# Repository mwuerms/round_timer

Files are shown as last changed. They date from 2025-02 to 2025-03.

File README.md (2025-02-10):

# round_timer

a small round timer, watch, 

## Ideas

* minumum
    * timer (alarm)
        * multiple at the same time
    * simple to use
    * nice sounds, like from mp3, ogg, ...
    * runs from battery (LiPo or similar)
    * round display, GUI
* also nice
    * watch
    * sensors like humidity, pressure, temperatur, light, magnetic (compass), ...
    * vibra for alarm

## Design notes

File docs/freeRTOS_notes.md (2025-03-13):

# Notes on FreeRTOS

## Misc

+ `osDelay(100*portTICK_PERIOD_MS);` os delays 100 ms

## Links

+ [STM32 FreeRTOS](https://stm32world.com/wiki/STM32_FreeRTOS)
+ https://electronics.stackexchange.com/questions/290592/use-stm32-interrupt-with-freertos

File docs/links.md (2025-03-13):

# Links

## STM32 examples

+ [STM32 FreeRTOS](https://stm32world.com/wiki/STM32_FreeRTOS)
+ [STM32L4 LL examples](https://github.com/STMicroelectronics/STM32CubeL4/tree/master/Projects/NUCLEO-L496ZG/Examples_LL)

## try this example/lib

+ [offpic / GC9A01-DMA-TFT-STM32-STM32F401-CLOCK](https://github.com/offpic/GC9A01-DMA-TFT-STM32-STM32F401-CLOCK)

## Inspiration

+ [Youtube GC9A01 DMA TFT STM32 STM32F401 CLOCK](https://www.youtube.com/watch?v=id6IK4ea0z8)
  + [offpic / GC9A01-DMA-TFT-STM32-STM32F401-CLOCK](https://github.com/offpic/GC9A01-DMA-TFT-STM32-STM32F401-CLOCK)
  + [STM32_Lib_TFT_ST7789](https://github.com/GolinskiyKonstantin/STM32_Lib_TFT_ST7789)
+ [Exboom (seems simple for STM32)](https://github.com/Exboom/GC9A01)
+ [seemingly simple GC9A01 example using Bodmer TFT_eSPI](https://elektro.turanis.de/html/prj441/index.html)
+ [Bodmer TFT_eSPI](https://github.com/Bodmer/TFT_eSPI)
+ [Waveshare GC9A01 Display (not the exact one)](https://www.waveshare.com/1.28inch-lcd-module.htm)
+ [STM32 + GC9A01 + Waveshare](https://www.waveshare.com/wiki/1.28inch_LCD_Module)
+ [VolosR + watchESP](https://github.com/VolosR/watchESP)
+ [printminopn](https://github.com/printminion/GC9A01-xiao-ESP32C3)

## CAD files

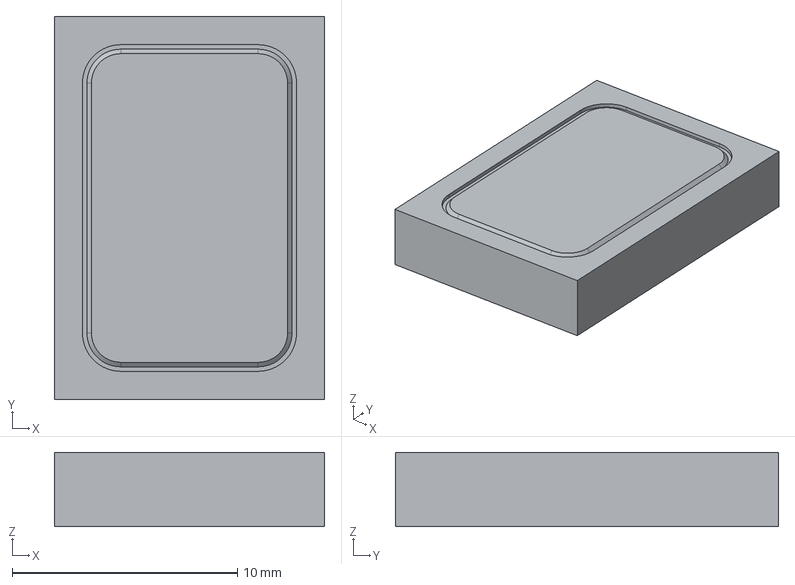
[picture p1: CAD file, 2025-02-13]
freecad/parts/speaker-CMS-171233-18SP-X8.step
12.0 x 17.0 x 3.30 mm

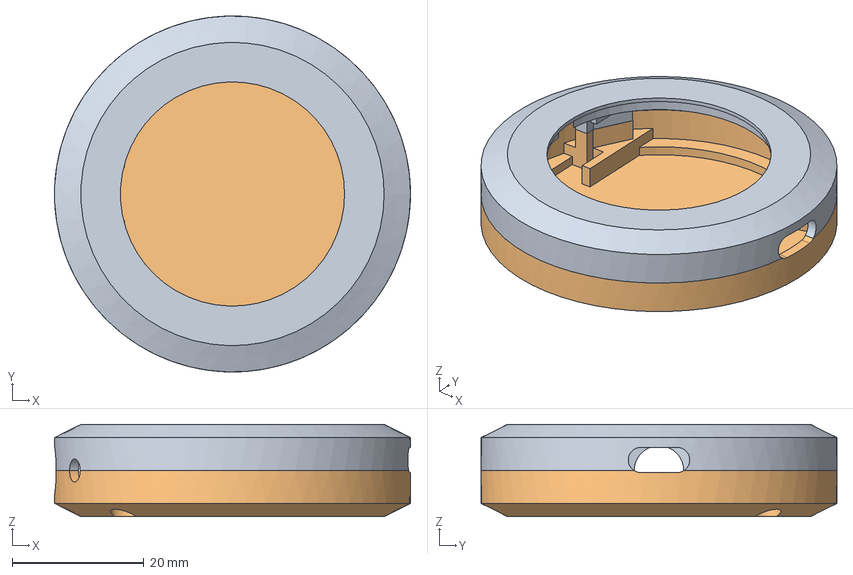
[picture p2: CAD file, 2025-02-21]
freecad/round_timer04.FCStd
54.0 x 54.0 x 14.0 mm
case top
case bottom

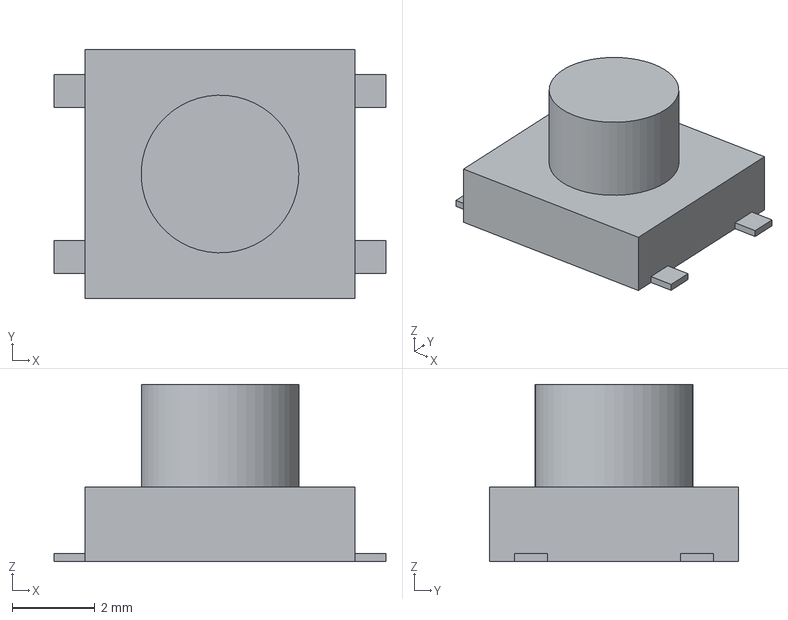
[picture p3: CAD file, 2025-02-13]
freecad/parts/button-EVPBT3G4A000.step
8.00 x 6.00 x 4.27 mm

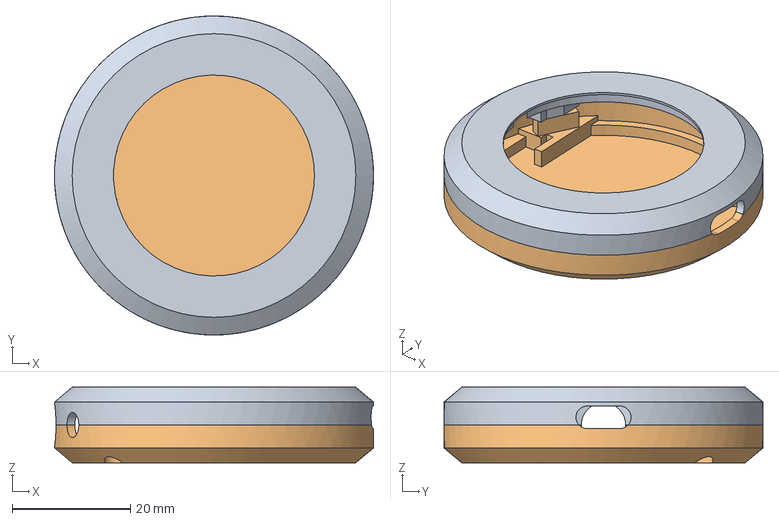
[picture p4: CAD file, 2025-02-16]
freecad/round_timer03.FCStd
54.0 x 54.0 x 12.8 mm
case top
case bottom

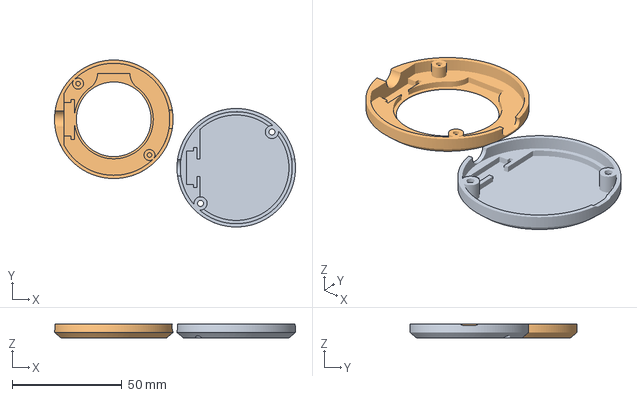
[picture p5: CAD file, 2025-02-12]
freecad/mockup02_case.3mf
109.8 x 76.0 x 6.40 mm
mockup02_case_bottom
mockup02_case_top

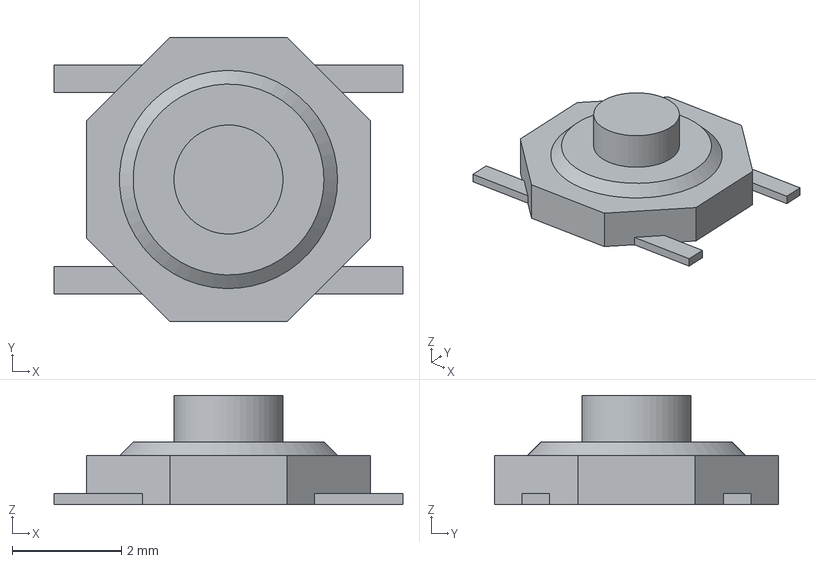
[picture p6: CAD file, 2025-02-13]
freecad/parts/button-PTS526SM20SMTR21_LFS.step
6.40 x 5.20 x 2.00 mm

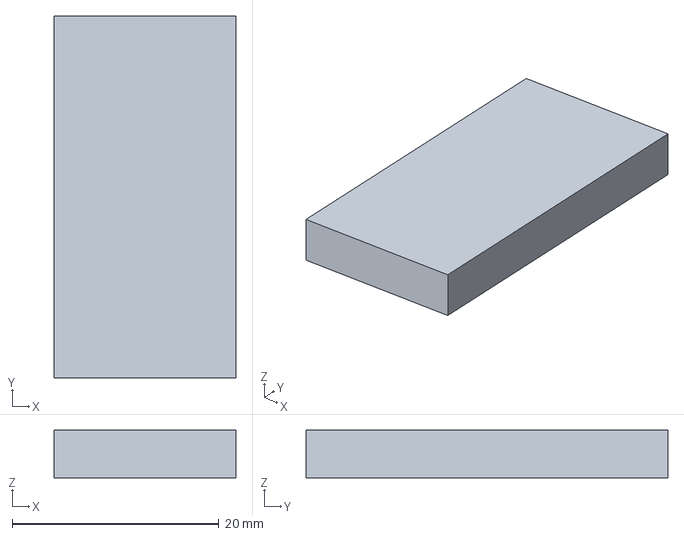
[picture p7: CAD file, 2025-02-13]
freecad/parts/battery.FCStd
17.6 x 35.0 x 4.60 mm

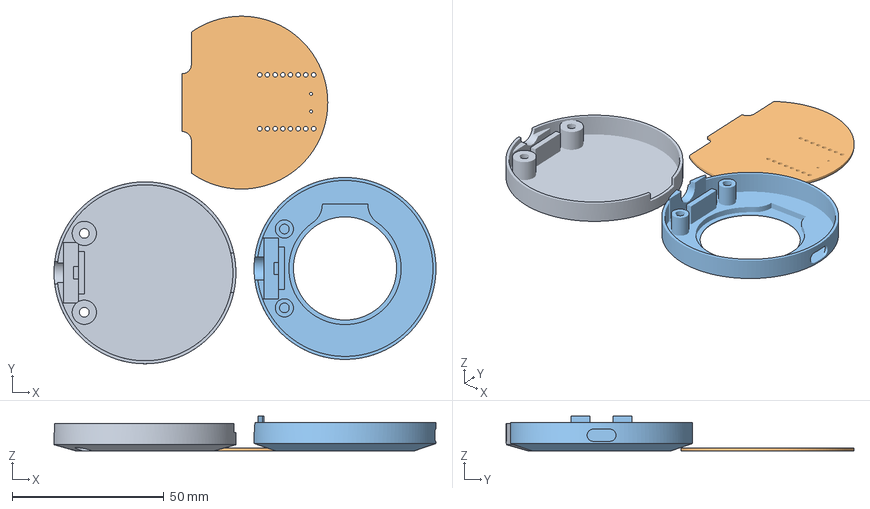
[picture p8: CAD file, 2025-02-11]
freecad/mockup01_case.3mf
126.0 x 114.6 x 11.4 mm
mockup01_case_bottom
mockup01_pcb
mockup01_case_top

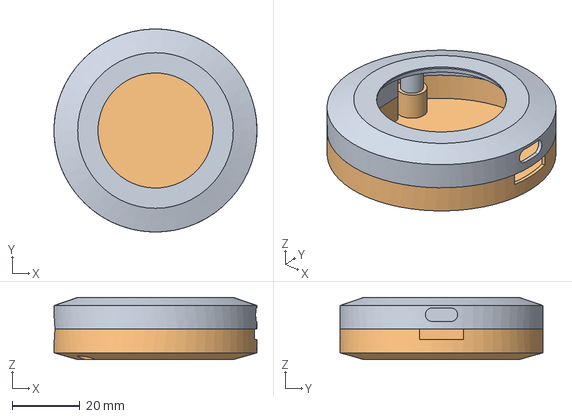
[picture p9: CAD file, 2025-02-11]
freecad/round_timer01.FCStd
60.0 x 60.0 x 18.4 mm
case top
case bottom

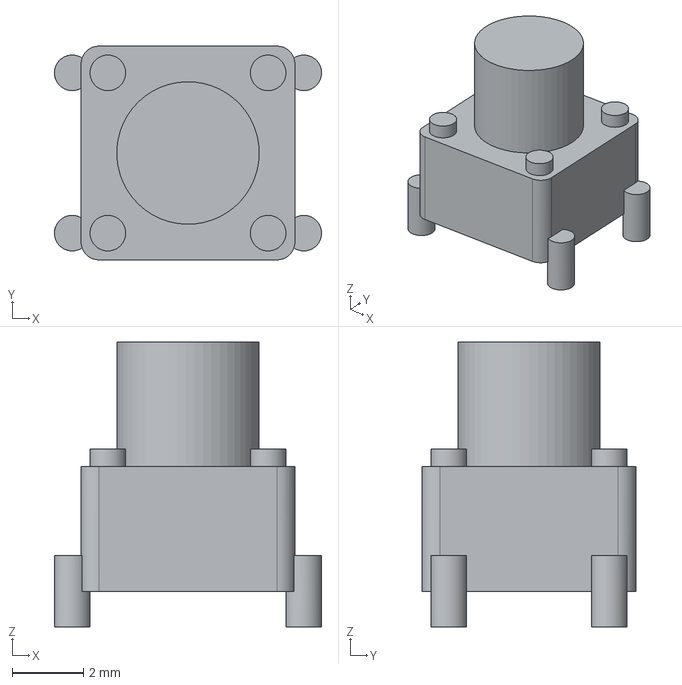
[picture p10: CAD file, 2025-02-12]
freecad/parts/button-TS02-66-70-BK-160-SCR.step
7.50 x 6.00 x 8.00 mm

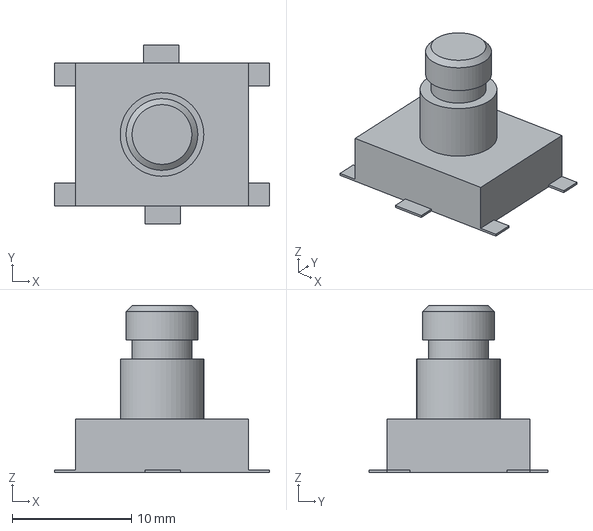
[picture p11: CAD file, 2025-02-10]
freecad/parts/rotary_encoder_PEC11S-929K-H0015.step
18.0 x 15.0 x 14.0 mm

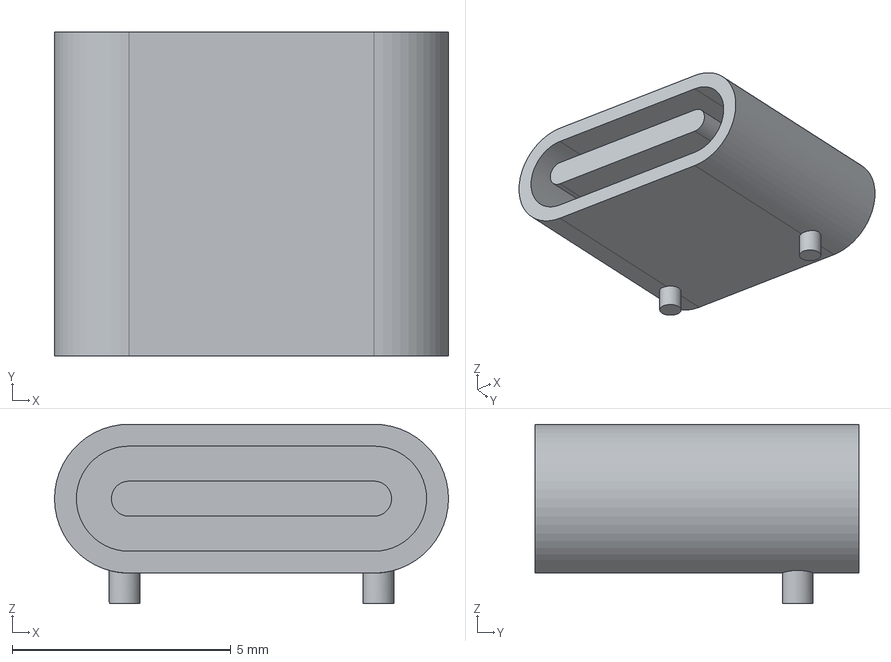
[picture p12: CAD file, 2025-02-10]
freecad/parts/USB4110-USB4110_CGT.step
9.00 x 7.40 x 4.10 mm

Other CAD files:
freecad/round_timer02.FCStd
freecad/parts/battery-IP461834.step
freecad/parts/button.FCStd
freecad/parts/speaker.FCStd
freecad/parts/rotary_encoder_PEC11S.FCStd
freecad/parts/USB4110.FCStd
freecad/parts/PER601-P117-N0015.stp
freecad/parts/dfplayer_pcb-player.step
freecad/parts/dfplayer_pcb.FCStd
freecad/parts/rotary_encoder_PEC11R-4215K-S0024.FCStd
freecad/parts/rotary_encoder_PEC11R-4215K-S0024.step
freecad/parts/round_1.28_inch_display.FCStd
freecad/parts/round_1.28_inch_display.step
freecad/parts/round_1.28_inch_display_cut.step
freecad/parts/speaker_CMS-3047-18L300-speaker.step

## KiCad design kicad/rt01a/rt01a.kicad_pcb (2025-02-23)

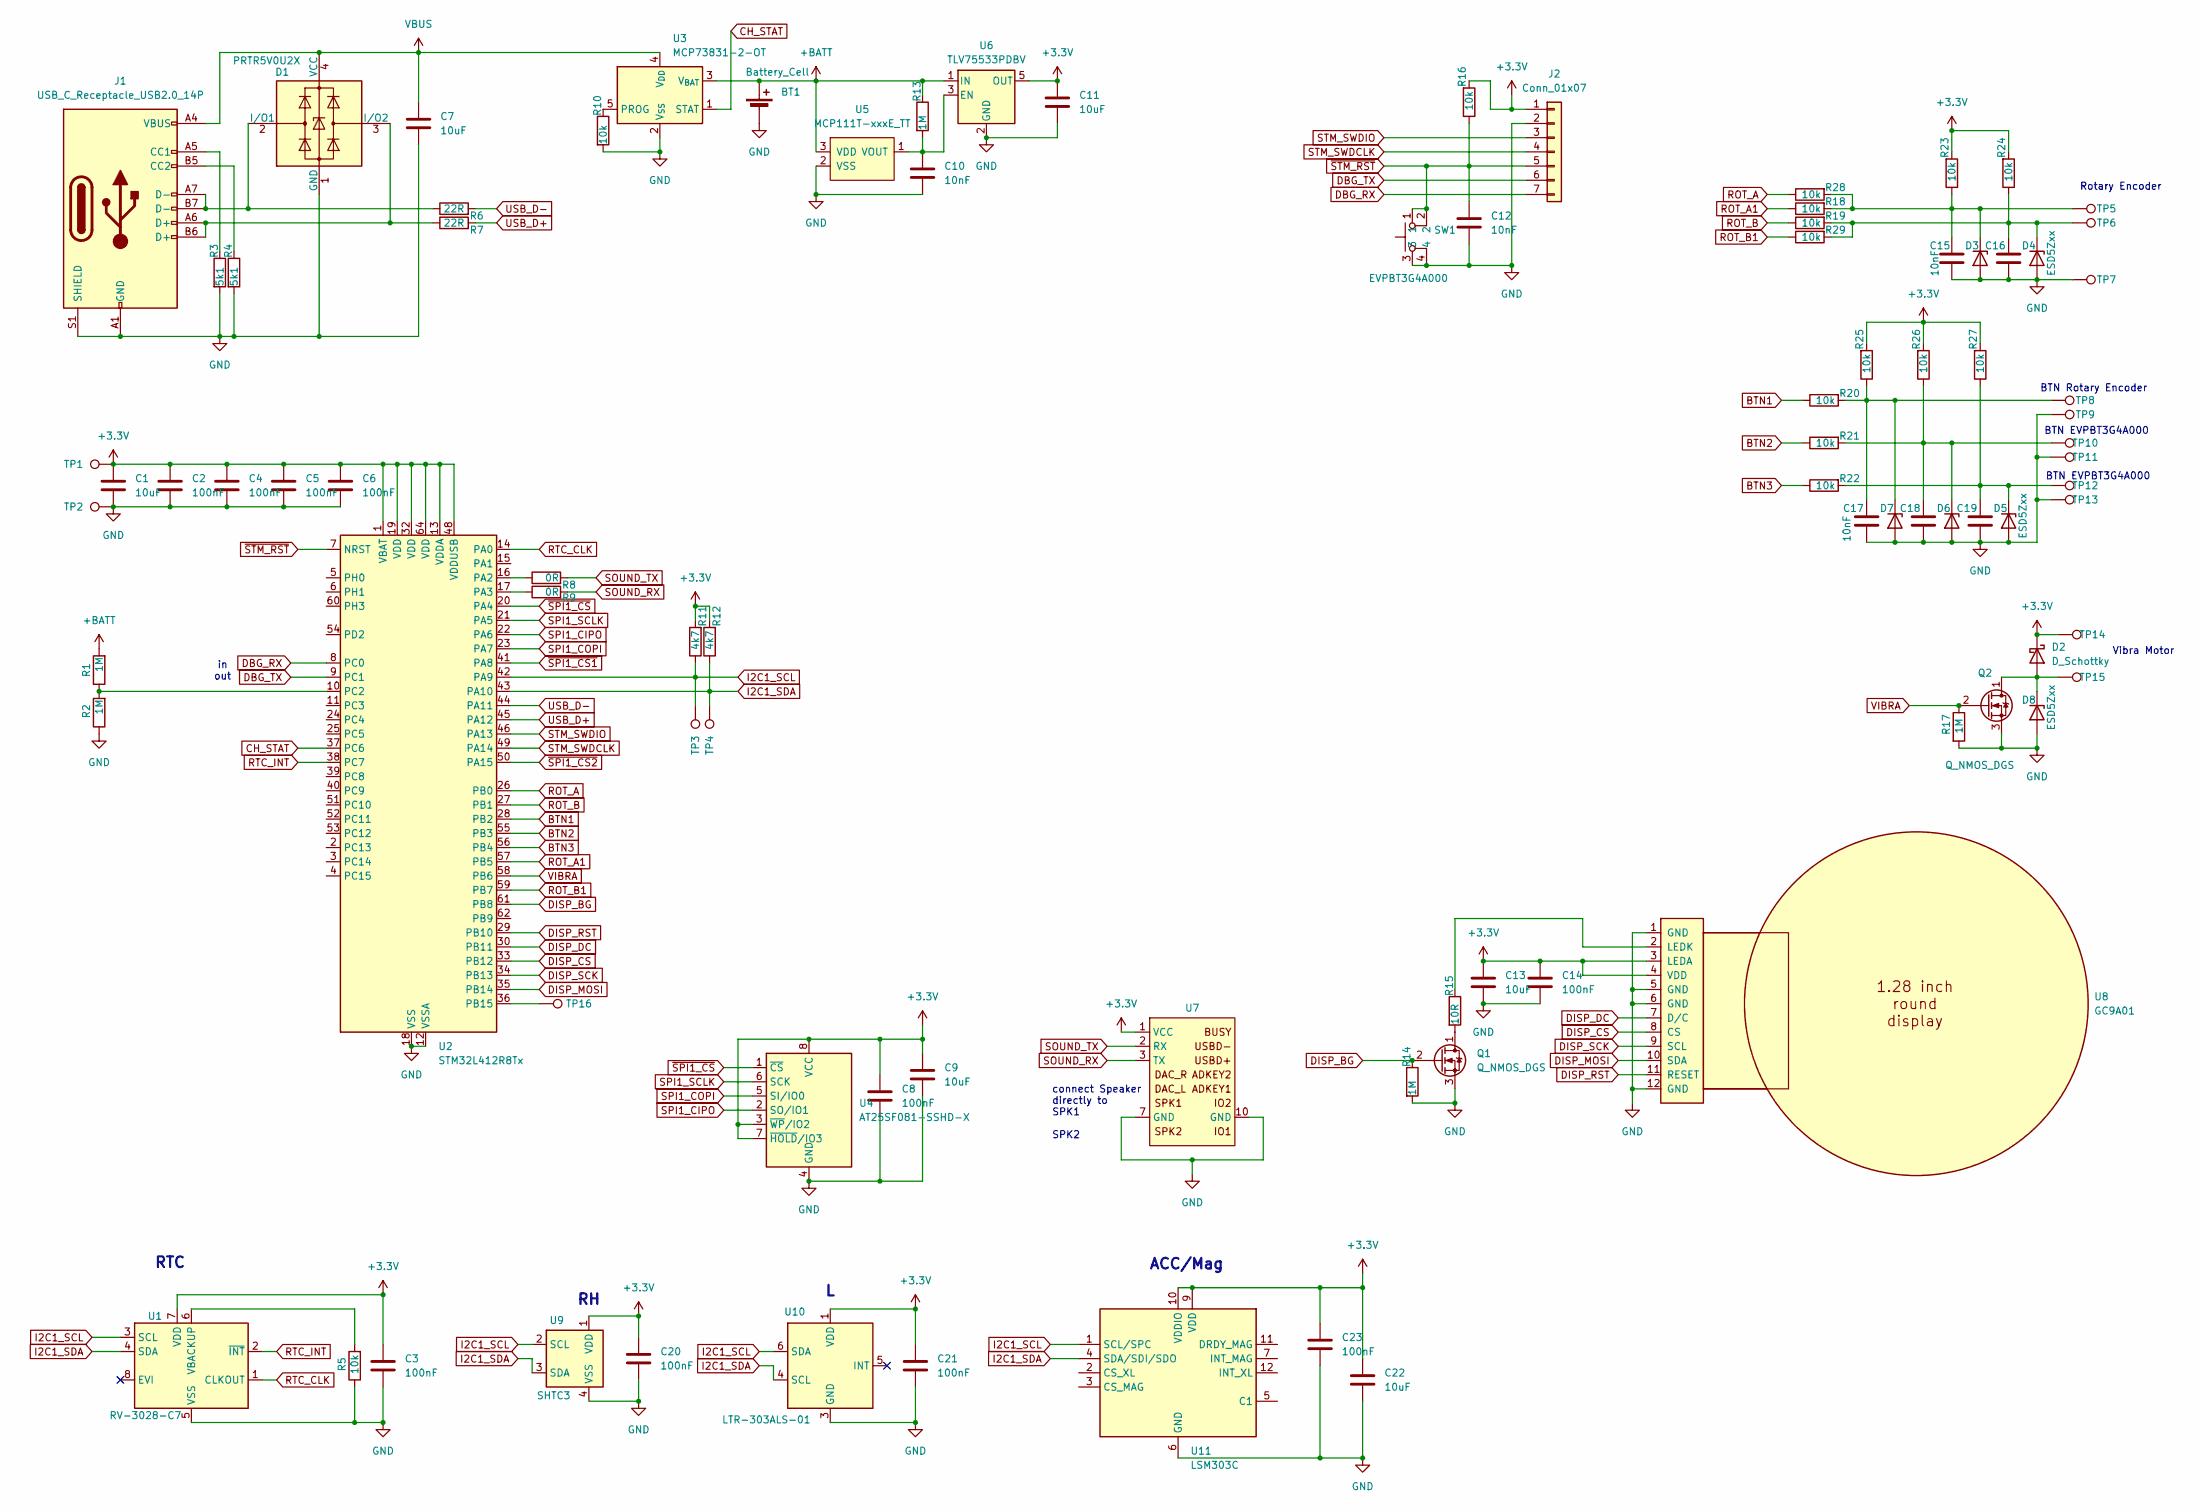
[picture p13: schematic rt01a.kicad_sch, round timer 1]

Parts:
BT1: Battery_Cell; PinHeader_1x02_P2.54mm_Vertical
C1, C7, C9, C11, C13, C22: 10uF; C_0805_2012Metric_Pad1.18x1.45mm_HandSolder
C2, C3, C4, C5, C6, C8, C14, C20, C21, C23: 100nF; C_0603_1608Metric_Pad1.08x0.95mm_HandSolder
C10, C12, C15, C16, C17, C18, C19: 10nF; C_0603_1608Metric_Pad1.08x0.95mm_HandSolder
D1: PRTR5V0U2X; SOT-143
D2: D_Schottky; D_SOD-523
D3, D4, D5, D6, D7, D8: ESD5Zxx; D_SMF
J1: USB_C_Receptacle_USB2.0_14P; USB_C_Receptacle_GCT_USB4110
J2: Conn_01x07; PinHeader_1x07_P1.27mm_Vertical
Q1, Q2: Q_NMOS_DGS; SOT-23-3
R1, R2, R13, R14, R17: 1M; R_0603_1608Metric_Pad0.98x0.95mm_HandSolder
R3, R4: 5k1; R_0603_1608Metric_Pad0.98x0.95mm_HandSolder
R5, R10, R16, R18, R19, R20, R21, R22, R23, R24, R25, R26, R27, R28, R29: 10k; R_0603_1608Metric_Pad0.98x0.95mm_HandSolder
R6, R7: 22R; R_0603_1608Metric_Pad0.98x0.95mm_HandSolder
R8, R9: 0R; R_0603_1608Metric_Pad0.98x0.95mm_HandSolder
R11, R12: 4k7; R_0603_1608Metric_Pad0.98x0.95mm_HandSolder
R15: 10R; R_0603_1608Metric_Pad0.98x0.95mm_HandSolder
SW1: EVPBT3G4A000; EVPBT3
TP1, TP2, TP3, TP4, TP5, TP6, TP7, TP8, TP9, TP10, TP11, TP12, TP13, TP14, TP15, TP16: TestPoint; TestPoint_Pad_D1.0mm
U1: RV-3028-C7; MicroCrystal_C7_SON-8_1.5x3.2mm_P0.9mm
U2: STM32L412R8Tx; LQFP-64_10x10mm_P0.5mm
U3: MCP73831-2-OT; SOT-23-5
U4: AT25SF081-SSHD-X; SOIC-8_3.9x4.9mm_P1.27mm
U5: MCP111T-xxxE_TT; SOT-23-3
U6: TLV75533PDBV; SOT-23-5
U7: DFPlayer_Mini-TF-16P_Minimal
U8: GC9A01; FP-128HR01A
U9: SHTC3; Sensirion_DFN-4-1EP_2x2mm_P1mm_EP0.7x1.6mm
U10: LTR-303ALS-01; Lite-On_LTR-303ALS-01
U11: LSM303C; LGA-12_2x2mm_P0.5mm

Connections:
+3.3V: C1.1, C2.1, C3.1, C4.1, C5.1, C6.1, C8.1, C9.1, C11.1, C13.1, C14.1, C20.1, C21.1, C22.1, C23.1, D2.1 (K), J2.1, R11.2, R12.2, R16.2, R23.2, R24.2, R25.2, R26.2, R27.2, TP1.1, TP14.1, U1.7 (VDD), U2.1 (VBAT), U2.13 (VDDA), U2.19 (VDD), U2.32 (VDD), U2.48 (VDDUSB), U2.64 (VDD), U4.3 (~WP/IO2), U4.7 (~HOLD/IO3), U4.8 (VCC), U6.5 (OUT), U7.1 (VCC), U8.3 (LEDA), U8.4 (VDD), U9.1 (VDD), U10.1 (VDD), U11.9 (VDD), U11.10 (VDDIO)
+BATT: BT1.1 (+), R1.2, R13.1, U3.3 (V_{BAT}), U5.3 (VDD), U6.1 (IN)
BTN1: R20.1, U2.28 (PB2)
BTN2: R21.1, U2.55 (PB3)
BTN3: R22.1, U2.56 (PB4)
CH_STAT: U2.37 (PC6), U3.1 (STAT)
DBG_RX: J2.7, U2.8 (PC0)
DBG_TX: J2.6, U2.9 (PC1)
DISP_BG: Q1.2 (G), R14.1, U2.61 (PB8)
DISP_CS: U2.33 (PB12), U8.8 (CS)
DISP_DC: U2.30 (PB11), U8.7 (D/C)
DISP_MOSI: U2.35 (PB14), U8.10 (SDA)
DISP_RST: U2.29 (PB10), U8.11 (RESET)
DISP_SCK: U2.34 (PB13), U8.9 (SCL)
GND: BT1.2 (-), C1.2, C2.2, C3.2, C4.2, C5.2, C6.2, C7.2, C8.2, C9.2, C10.2, C11.2, C12.2, C13.2, C14.2, C15.2, C16.2, C17.2, C18.2, C19.2, C20.2, C21.2, C22.2, C23.2, D1.1 (GND), D3.2 (A), D4.2 (A), D5.2 (A), D6.2 (A), D7.2 (A), D8.2 (A), J1.A1 (GND), J1.A12 (GND), J1.B1 (GND), J1.B12 (GND), J1.S1 (SHIELD), J2.2, Q1.3 (S), Q2.3 (S), R2.1, R3.2, R4.2, R5.1, R10.2, R14.2, R17.2, SW1.3, SW1.4, TP2.1, TP7.1, TP9.1, TP11.1, TP13.1, U1.5 (VSS), U2.12 (VSSA), U2.18 (VSS), U2.31 (VSS), U2.47 (VSS), U2.63 (VSS), U3.2 (V_{SS}), U4.4 (GND), U5.2 (VSS), U6.2 (GND), U7.7 (GND), U7.10 (GND), U8.1 (GND), U8.5 (GND), U8.6 (GND), U8.12 (GND), U9.4 (VSS), U10.3 (GND), U11.6 (GND), U11.8 (GND)
I2C1_SCL: R11.1, TP3.1, U1.3 (SCL), U2.42 (PA9), U9.2 (SCL), U10.6 (SDA), U11.1 (SCL/SPC)
I2C1_SDA: R12.1, TP4.1, U1.4 (SDA), U2.43 (PA10), U9.3 (SDA), U10.4 (SCL), U11.4 (SDA/SDI/SDO)
unnamed: D1.2 (I/O1), J1.A7 (D-), J1.B7 (D-), R6.1
unnamed: D1.3 (I/O2), J1.A6 (D+), J1.B6 (D+), R7.1
unnamed: D2.2 (A), D8.1 (K), Q2.1 (D), TP15.1
unnamed: C15.1, D3.1 (K), R18.2, R23.1, R28.2, TP5.1
unnamed: C16.1, D4.1 (K), R19.2, R24.1, R29.2, TP6.1
unnamed: C19.1, D5.1 (K), R22.2, R27.1, TP12.1
unnamed: C18.1, D6.1 (K), R21.2, R26.1, TP10.1
unnamed: C17.1, D7.1 (K), R20.2, R25.1, TP8.1
unnamed: J1.A5 (CC1), R3.1
unnamed: J1.B5 (CC2), R4.1
unnamed: Q1.1 (D), R15.2
unnamed: R5.2, U1.6 (VBACKUP)
unnamed: R8.1, U2.16 (PA2)
unnamed: R9.1, U2.17 (PA3)
unnamed: TP16.1, U2.36 (PB15)
unnamed: R1.1, R2.2, U2.10 (PC2)
unnamed: R10.1, U3.5 (PROG)
unnamed: C10.1, R13.2, U5.1 (VOUT), U6.3 (EN)
unnamed: R15.1, U8.2 (LEDK)
ROT_A: R28.1, U2.26 (PB0)
ROT_A1: R18.1, U2.57 (PB5)
ROT_B: R19.1, U2.27 (PB1)
ROT_B1: R29.1, U2.59 (PB7)
RTC_CLK: U1.1 (CLKOUT), U2.14 (PA0)
RTC_INT: U1.2 (~INT), U2.38 (PC7)
SOUND_RX: R9.2, U7.3 (TX)
SOUND_TX: R8.2, U7.2 (RX)
SPI1_CIPO: U2.22 (PA6), U4.2 (SO/IO1)
SPI1_COPI: U2.23 (PA7), U4.5 (SI/IO0)
SPI1_SCLK: U2.21 (PA5), U4.6 (SCK)
STM_SWDCLK: J2.4, U2.49 (PA14)
STM_SWDIO: J2.3, U2.46 (PA13)
USB_D+: R7.2, U2.45 (PA12)
USB_D-: R6.2, U2.44 (PA11)
VBUS: C7.1, D1.4 (VCC), J1.A4 (VBUS), J1.A9 (VBUS), J1.B4 (VBUS), J1.B9 (VBUS), U3.4 (V_{DD})
VIBRA: Q2.2 (G), R17.1, U2.58 (PB6)
~SPI1_CS1: U2.41 (PA8)
~SPI1_CS2: U2.50 (PA15)
~SPI1_CS: U2.20 (PA4), U4.1 (~CS)
~STM_RST: C12.1, J2.5, R16.1, SW1.1, SW1.2, U2.7 (NRST)

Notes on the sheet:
BTN EVPBT3G4A000
Rotary Encoder
RTC
connect Speaker directly to SPK1 SPK2
Vibra Motor
BTN Rotary Encoder
ACC/Mag
in out

Board: 4 copper layers, 93 parts (85 on the bottom side), 55 nets, no tracks yet.

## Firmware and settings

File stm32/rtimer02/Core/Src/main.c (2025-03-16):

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
/* Includes ------------------------------------------------------------------*/
#include "main.h"
#include "cmsis_os.h"
#include "spi.h"
#include "gpio.h"

/* USER CODE BEGIN Includes */
#include "disp.h"

/* USER CODE END Includes */


void SystemClock_Config(void);
void MX_FREERTOS_Init(void);
/**
  * @brief  The application entry point.
  * @retval int
  */
int main(void)
{

  /* MCU Configuration--------------------------------------------------------*/

  /* Reset of all peripherals, Initializes the Flash interface and the Systick. */
  HAL_Init();

  /* Configure the system clock */
  SystemClock_Config();

  /* Initialize all configured peripherals */
  MX_GPIO_Init();
  MX_SPI2_Init();
  /* USER CODE BEGIN 2 */

	HAL_GPIO_WritePin(DBG0_GPIO_Port, DBG0_Pin, GPIO_PIN_RESET);
	HAL_GPIO_WritePin(DBG1_GPIO_Port, DBG1_Pin, GPIO_PIN_RESET);
	HAL_GPIO_WritePin(DBG0_GPIO_Port, DBG0_Pin, GPIO_PIN_SET);
	HAL_GPIO_WritePin(DBG1_GPIO_Port, DBG1_Pin, GPIO_PIN_SET);
	HAL_GPIO_WritePin(DBG0_GPIO_Port, DBG0_Pin, GPIO_PIN_RESET);
	HAL_GPIO_WritePin(DBG1_GPIO_Port, DBG1_Pin, GPIO_PIN_RESET);


	for(volatile uint32_t cnt = 0; cnt < 10000; cnt++); // 6 ms
	HAL_GPIO_WritePin(DBG0_GPIO_Port, DBG0_Pin, GPIO_PIN_SET);
	for(volatile uint32_t cnt = 0; cnt < 20000; cnt++); // 13 ms
	HAL_GPIO_WritePin(DBG1_GPIO_Port, DBG1_Pin, GPIO_PIN_SET);
	for(volatile uint32_t cnt = 0; cnt < 30000; cnt++); // 19 ms
	HAL_GPIO_WritePin(DBG0_GPIO_Port, DBG0_Pin, GPIO_PIN_RESET);
	for(volatile uint32_t cnt = 0; cnt < 500000; cnt++); // 347 ms
	HAL_GPIO_WritePin(DBG1_GPIO_Port, DBG1_Pin, GPIO_PIN_RESET);

	// 50 ms -> 30000/19 * 50 = 79000
	// 100 ms -> 160000
	// 150 ms -> 240000
	//for(volatile uint32_t cnt = 0; cnt < (1*80000); cnt++); // 56 ms
	for(volatile uint32_t cnt = 0; cnt < (1*79000); cnt++); // 55 ms
	HAL_GPIO_WritePin(DBG0_GPIO_Port, DBG0_Pin, GPIO_PIN_SET);
	//for(volatile uint32_t cnt = 0; cnt < (2*80000); cnt++); // 110 ms
	for(volatile uint32_t cnt = 0; cnt < (2*79000); cnt++); // 110 ms
	HAL_GPIO_WritePin(DBG1_GPIO_Port, DBG1_Pin, GPIO_PIN_SET);
	//for(volatile uint32_t cnt = 0; cnt < (3*80000); cnt++); // 166 ms
	for(volatile uint32_t cnt = 0; cnt < (3*79000); cnt++); // 166 ms
	HAL_GPIO_WritePin(DBG1_GPIO_Port, DBG1_Pin, GPIO_PIN_RESET);
	HAL_GPIO_WritePin(DBG0_GPIO_Port, DBG0_Pin, GPIO_PIN_RESET);

	disp_init();
	disp_rotation(6, 0, 0); // correct rotation for this project

	app_init();
  	usr_in_init();


	HAL_GPIO_WritePin(DBG0_GPIO_Port, DBG0_Pin, GPIO_PIN_SET);
	HAL_GPIO_WritePin(DBG1_GPIO_Port, DBG1_Pin, GPIO_PIN_SET);

	//disp_print(20, 80, DISP_COLOR_RED, DISP_COLOR_WHITE, 1, &Font_16x26, 0, ".-=' INIT '=-.");

	HAL_GPIO_WritePin(DBG0_GPIO_Port, DBG0_Pin, GPIO_PIN_RESET);
	HAL_GPIO_WritePin(DBG1_GPIO_Port, DBG1_Pin, GPIO_PIN_RESET);
  /* USER CODE END 2 */

  /* Init scheduler */
  osKernelInitialize();

  /* Call init function for freertos objects (in cmsis_os2.c) */
  MX_FREERTOS_Init();

  /* Start scheduler */
  osKernelStart();

  /* We should never get here as control is now taken by the scheduler */

  /* Infinite loop */
  /* USER CODE BEGIN WHILE */
  while (1)
  {
    /* USER CODE END WHILE */

    /* USER CODE BEGIN 3 */
  }
  /* USER CODE END 3 */
}

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
/**
  * @brief  Period elapsed callback in non blocking mode
  * @note   This function is called  when TIM1 interrupt took place, inside
  * HAL_TIM_IRQHandler(). It makes a direct call to HAL_IncTick() to increment
  * a global variable "uwTick" used as application time base.
  * @param  htim : TIM handle
  * @retval None
  */
void HAL_TIM_PeriodElapsedCallback(TIM_HandleTypeDef *htim)
{
  if (htim->Instance == TIM1) {
    HAL_IncTick();
  }
}

/**
  * @brief  This function is executed in case of error occurrence.
  * @retval None
  */
void Error_Handler(void)
{
  /* USER CODE BEGIN Error_Handler_Debug */
  /* User can add his own implementation to report the HAL error return state */
  __disable_irq();
  while (1)
  {
  }
  /* USER CODE END Error_Handler_Debug */
}

#ifdef  USE_FULL_ASSERT
/**
  * @brief  Reports the name of the source file and the source line number
  *         where the assert_param error has occurred.
  * @param  file: pointer to the source file name
  * @param  line: assert_param error line source number
  * @retval None
  */
void assert_failed(uint8_t *file, uint32_t line)
{
  /* USER CODE BEGIN 6 */
  /* User can add his own implementation to report the file name and line number,
     ex: printf("Wrong parameters value: file %s on line %d\r\n", file, line) */
  /* USER CODE END 6 */
}
#endif /* USE_FULL_ASSERT */

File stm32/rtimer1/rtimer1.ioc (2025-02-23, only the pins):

Mcu.UserName=STM32L412R8Tx
PA0.GPIO_Label=RTC_CLK
PA0.Signal=S_TIM2_ETR
PA2.GPIO_Label=SOUND_TX
PA2.Signal=USART2_TX
PA3.GPIO_Label=SOUND_RX
PA3.Signal=USART2_RX
PB0.GPIO_Label=ROT_A
PB0.Signal=GPXTI0
PB1.GPIO_Label=ROT_B
PB1.Signal=GPXTI1
PB10.GPIO_Label=DISP_RST
PB10.Signal=GPIO_Output
PB11.GPIO_Label=DISP_DC
PB11.Signal=GPIO_Output
PB12.GPIO_Label=DISP_CS
PB12.Signal=GPIO_Output
PB13.GPIO_Label=DISP_SCK
PB13.Signal=SPI2_SCK
PB14.GPIO_Label=DISP_MISO
PB14.Signal=SPI2_MISO
PB15.GPIO_Label=DISP_MOSI
PB15.Signal=SPI2_MOSI
PB2.GPIO_Label=BTN1
PB2.Signal=GPXTI2
PB5.GPIO_Label=ENC_IN1
PB5.Signal=LPTIM1_IN1
PB6.GPIO_Label=VIBRA
PB6.Signal=GPIO_Output
PB7.GPIO_Label=ENC_IN2
PB7.Signal=LPTIM1_IN2
PB8.Signal=S_TIM16_CH1
PC0.GPIO_Label=DBG_RX
PC0.Signal=LPUART1_RX
PC1.GPIO_Label=DBG_TX
PC1.Signal=LPUART1_TX
PC2.GPIO_Label=BAT
PC2.Signal=ADCx_IN3
PC6.GPIO_Label=CH_STAT
PC6.Signal=GPXTI6
PC7.GPIO_Label=RTC_INT
PC7.Signal=GPXTI7

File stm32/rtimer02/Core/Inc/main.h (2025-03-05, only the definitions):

#define DISP_RST_Pin GPIO_PIN_10
#define DISP_RST_GPIO_Port GPIOB
#define DISP_DC_Pin GPIO_PIN_11
#define DISP_DC_GPIO_Port GPIOB
#define DISP_CS_Pin GPIO_PIN_12
#define DISP_CS_GPIO_Port GPIOB
#define DISP_SCK_Pin GPIO_PIN_13
#define DISP_SCK_GPIO_Port GPIOB
#define DISP_MISO_Pin GPIO_PIN_14
#define DISP_MISO_GPIO_Port GPIOB
#define DISP_MOSI_Pin GPIO_PIN_15
#define DISP_MOSI_GPIO_Port GPIOB
#define DBG0_Pin GPIO_PIN_10
#define DBG0_GPIO_Port GPIOC
#define DBG1_Pin GPIO_PIN_11
#define DBG1_GPIO_Port GPIOC
#define BTN0_Pin GPIO_PIN_3
#define BTN0_GPIO_Port GPIOB
#define BTN0_EXTI_IRQn EXTI3_IRQn
#define BTN1_Pin GPIO_PIN_4
#define BTN1_GPIO_Port GPIOB
#define BTN1_EXTI_IRQn EXTI4_IRQn
#define ENC_A_Pin GPIO_PIN_5
#define ENC_A_GPIO_Port GPIOB
#define ENC_A_EXTI_IRQn EXTI9_5_IRQn
#define BTN2_Pin GPIO_PIN_6
#define BTN2_GPIO_Port GPIOB
#define BTN2_EXTI_IRQn EXTI9_5_IRQn
#define ENC_B_Pin GPIO_PIN_7
#define ENC_B_GPIO_Port GPIOB
#define ENC_B_EXTI_IRQn EXTI9_5_IRQn

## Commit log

2025-02-10 added round 1.28 inch display
    [round_1.28_inch_display.FCStd, round_1.28_inch_display.step, round_1.28_inch_display_cut.step]
2025-02-10 dfplayer added
    [dfplayer_pcb-player.step, dfplayer_pcb.FCStd]
2025-02-10 speaker added
    [speaker_CMS-3047-18L300-speaker.step, speaker_CMS-3047-18L300.FCStd]
2025-02-10 rotary encoder added
    from manufacturer
    https://bourns.com/resources/design-tools/engineering-files-list?Folder=PER60
    [PER601-P117-N0015.stp]
2025-02-10 round_timer01 added, 1st try out
    [round_timer01.FCStd]
2025-02-10 rotary encoder added, gitignore added
    [rotary_encoder_PEC11R-4215K-S0024.FCStd, rotary_encoder_PEC11R-4215K-S0024.step, round_timer01.FCStd]
2025-02-10 tryout 1
    [round_timer01.FCStd]
2025-02-10 usbc USB4110 added
    [USB4110-USB4110_CGT.step, USB4110.FCStd, round_timer01.FCStd]
2025-02-10 PEC11S added
    [rotary_encoder_PEC11S-929K-H0015.step, rotary_encoder_PEC11S.FCStd]
2025-02-11 mockup 1, case top part, 3d print
    [mockup01_case.3mf, round_timer01.FCStd]
2025-02-12 part speaker, new part added, therefore renamed
    [speaker.FCStd]
2025-02-12 case mockup2, top case done
    [round_timer02.FCStd, speaker.FCStd]
2025-02-12 mockup case 2
    [mockup02_case.3mf, round_timer02.FCStd]
2025-02-12 button added
    [button-TS02-66-70-BK-160-SCR.step, button.FCStd]
2025-02-13 new parts added
    [battery-IP461834.step, battery.FCStd, button-EVPBT3G4A000.step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]
2025-02-13 new parts added, place new button
    [round_timer03.FCStd]
2025-02-14 case 03
    [round_timer03.FCStd]
2025-02-16 started kicad tr01a project
    [round_timer03.FCStd, rt01a.kicad_pcb, rt01a.kicad_sch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]
2025-02-16 removed rt01a_1, _2, not needed anymore
    [rt01a.kicad_sch, rt01a_1.kicad_sch, rt01a_2.kicad_sch]
2025-02-16 rt01a added footprint, some placements done
    [rt01a.kicad_pcb, rt01a.kicad_sch]
2025-02-21 case 4
    [round_timer04.FCStd]
2025-02-23 schematics seems done
    [rt01a.kicad_pcb, rt01a.kicad_sch]
2025-02-23 rtimer1 stm32cubeide project started, pindefinitions
2025-02-26 stm32 disp, testing project added
2025-02-28 LPTM2 as timer works, event timer works, sending events to app works
2025-03-13 rtimer02 1st version of timer_app display, all there but not yet very good
    [lptim2_prescaler.ods]

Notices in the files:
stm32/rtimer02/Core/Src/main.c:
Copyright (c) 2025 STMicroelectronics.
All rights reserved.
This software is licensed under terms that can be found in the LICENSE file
